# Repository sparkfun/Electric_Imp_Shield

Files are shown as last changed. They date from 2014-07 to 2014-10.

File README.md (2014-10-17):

Electric Imp Shield
===================

[Electric Imp Shield
*Electric Imp Shield (DEV-12887)*](https://www.sparkfun.com/products/12887)

The Electric Imp shield allows you to connect your Arduino to the Imp Cloud Service and connect to HTTP APIs. 

Repository Contents
-------------------
* **/Hardware** - All Eagle design files (.brd, .sch)
* **/Production** - Test bed files and production panel files

Product Versions
----------------
* [DEV-11401](https://www.sparkfun.com/products/retired/11401)- Version 1.1. Designed for Uno (not R3). Retired. 

Version History
---------------
* [v1.1](https://github.com/sparkfun/Electric_Imp_Shield/tree/V_1.1) Version 1.1

License Information
-------------------
The hardware is released under [Creative Commons ShareAlike 4.0 International](https://creativecommons.org/licenses/by-sa/4.0/).The code is beerware; if you see me (or any other SparkFun employee) at the local, and you've found our code helpful, please buy us a round!

Distributed as-is; no warranty is given.

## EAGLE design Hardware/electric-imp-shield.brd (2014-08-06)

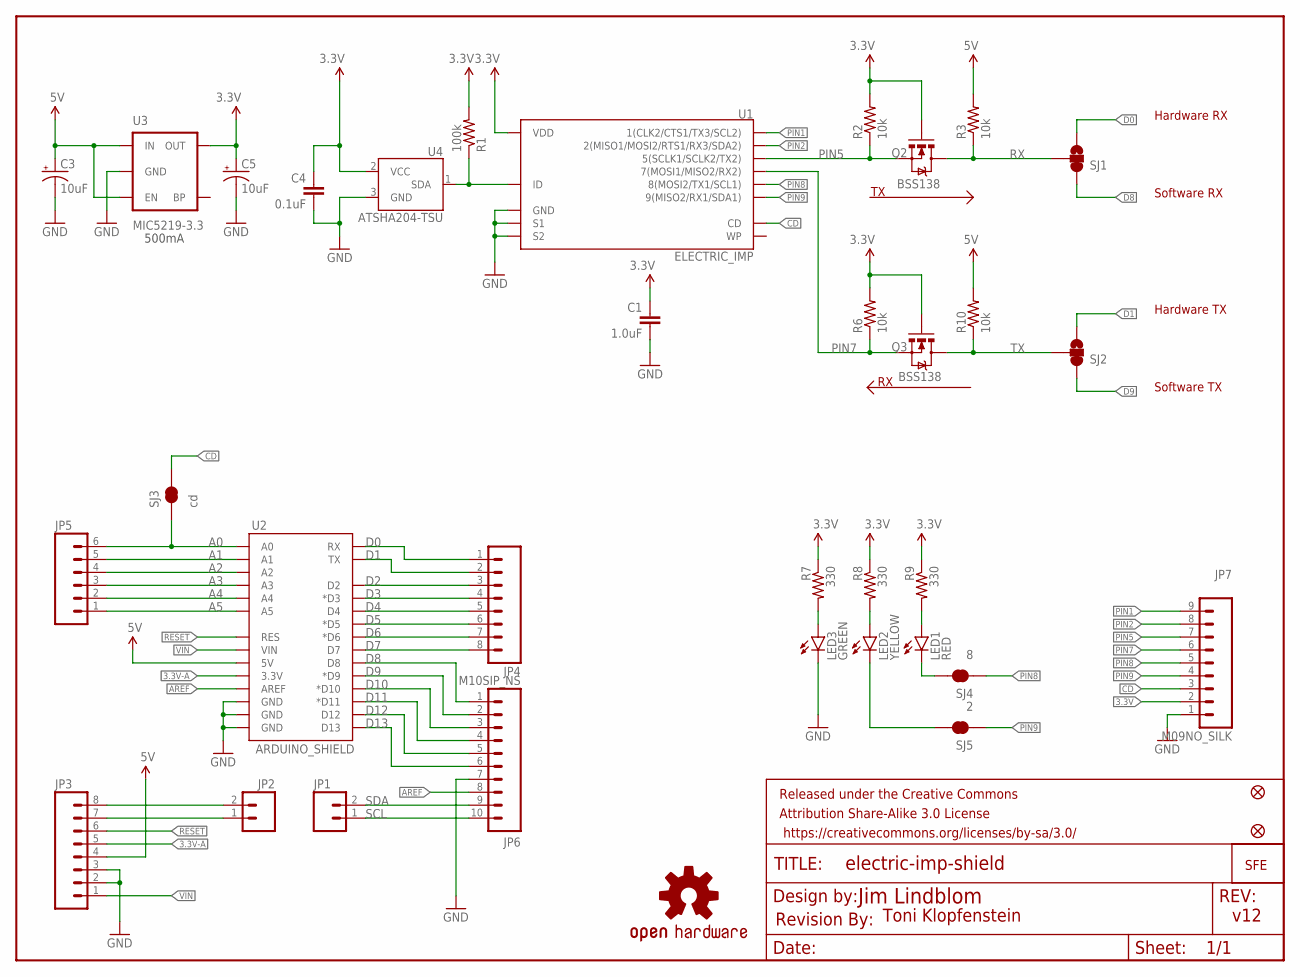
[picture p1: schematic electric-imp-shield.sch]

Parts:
C1: 1.0uF; 0603-CAP
C3, C5: 10uF; EIA3216
C4: 0.1uF; 0603-CAP
FID1, FID2: FIDUCIAL1X2; FIDUCIAL-1X2
FRAME1: FRAME-LETTER; CREATIVE_COMMONS
JP1, JP2: M021X02_NO_SILK; 1X02_NO_SILK
JP3, JP4: M08SIP_NS; 1X08_NO_SILK
JP5: M06SIP_NS; 1X06_NO_SILK
JP6: M10SIP_NS; 1X10_NO_SILK
JP7: M09NO_SILK; 1X09_NO_SILK
JP10: LOGO-SFENW2; SFE-NEW-WEB
LED1: RED; LED-0603
LED2: YELLOW; LED-0603
LED3: GREEN; LED-0603
Q2, Q3: BSS138; SOT23-3
R1: 100k; 0603-RES
R2, R3, R6, R10: 10k; 0603-RES
R7, R8, R9: 330; 0603-RES
SJ1, SJ2: SOLDERJUMPER_2WAYS; SJ_3
SJ3: cd; SJ_2S-TRACE
SJ4: 8; SJ_2S-TRACE
SJ5: 2; SJ_2S-TRACE
U1: ELECTRIC_IMP; SD_1:1
U2: ARDUINO_SHIELD; DUEMILANOVE_SHIELD_NOHOLES_NOLABELS
U3: MIC5219-3.3; SOT23-5
U4: ATSHA204-TSU; SOT23-3
U$6: REVISION
U$7: OSHW-LOGOS; OSHW-LOGO-S

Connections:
3.3V: C1.1, C4.1, C5.A (+), JP7.2, Q2.1 (G), Q3.1 (G), R1.2, R2.2, R6.2, R7.1, R8.1, R9.1, U1.4 (VDD), U3.5 (OUT), U4.2 (VCC)
3.3V-A: JP3.5, U2.3.3V
5V: C3.A (+), JP3.4, R3.2, R10.2, U2.5V, U3.1 (IN), U3.3 (EN)
A0: JP5.6, SJ3.1, U2.A0
A1: JP5.5, U2.A1
A2: JP5.4, U2.A2
A3: JP5.3, U2.A3
A4: JP5.2, U2.A4
A5: JP5.1, U2.A5
ACTIVITY: LED1.C, SJ4.2
AREF: JP6.8, U2.AREF
CD: JP7.3, SJ3.2, U1.CD
D0: JP4.1, SJ1.3, U2.RX
D1: JP4.2, SJ2.3, U2.TX
D2: JP4.3, U2.D2
D3: JP4.4, U2.D3 (*D3)
D4: JP4.5, U2.D4
D5: JP4.6, U2.D5 (*D5)
D6: JP4.7, U2.D6 (*D6)
D7: JP4.8, U2.D7
D8: JP6.1, SJ1.1, U2.D8
D9: JP6.2, SJ2.1, U2.D9 (*D9)
D10: JP6.3, U2.D10 (*D10)
D11: JP6.4, U2.D11 (*D11)
D12: JP6.5, U2.D12
D13: JP6.6, U2.D13
GND: C1.2, C3.C (-), C4.2, C5.C (-), JP3.2, JP3.3, JP6.7, JP7.1, LED3.C, U1.3 (GND), U1.SH@1 (S1), U1.SH@2 (S2), U2.GND@0 (GND), U2.GND@1 (GND), U2.GND@2 (GND), U3.2 (GND), U4.3 (GND)
LINK: LED2.C, SJ5.2
unnamed: R1.1, U1.6 (ID), U4.1 (SDA)
unnamed: JP2.2, JP3.8
unnamed: JP2.1, JP3.7
unnamed: LED3.A, R7.2
unnamed: LED2.A, R8.2
unnamed: LED1.A, R9.2
PIN1: JP7.9, U1.1 (1(CLK2/CTS1/TX3/SCL2))
PIN2: JP7.8, U1.2 (2(MISO1/MOSI2/RTS1/RX3/SDA2))
PIN5: JP7.7, Q2.2 (S), R2.1, U1.5 (5(SCLK1/SCLK2/TX2))
PIN7: JP7.6, Q3.2 (S), R6.1, U1.7 (7(MOSI1/MISO2/RX2))
PIN8: JP7.5, SJ4.1, U1.8 (8(MOSI2/TX1/SCL1))
PIN9: JP7.4, SJ5.1, U1.9 (9(MISO2/RX1/SDA1))
RESET: JP3.6, U2.RES
RX: Q2.3 (D), R3.1, SJ1.2
SCL: JP1.1, JP6.10
SDA: JP1.2, JP6.9
TX: Q3.3 (D), R10.1, SJ2.2
VIN: JP3.1, U2.VIN

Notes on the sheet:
Hardware RX
Software RX
Hardware TX
Software TX
500mA
Jim Lindblom
v12
Toni Klopfenstein

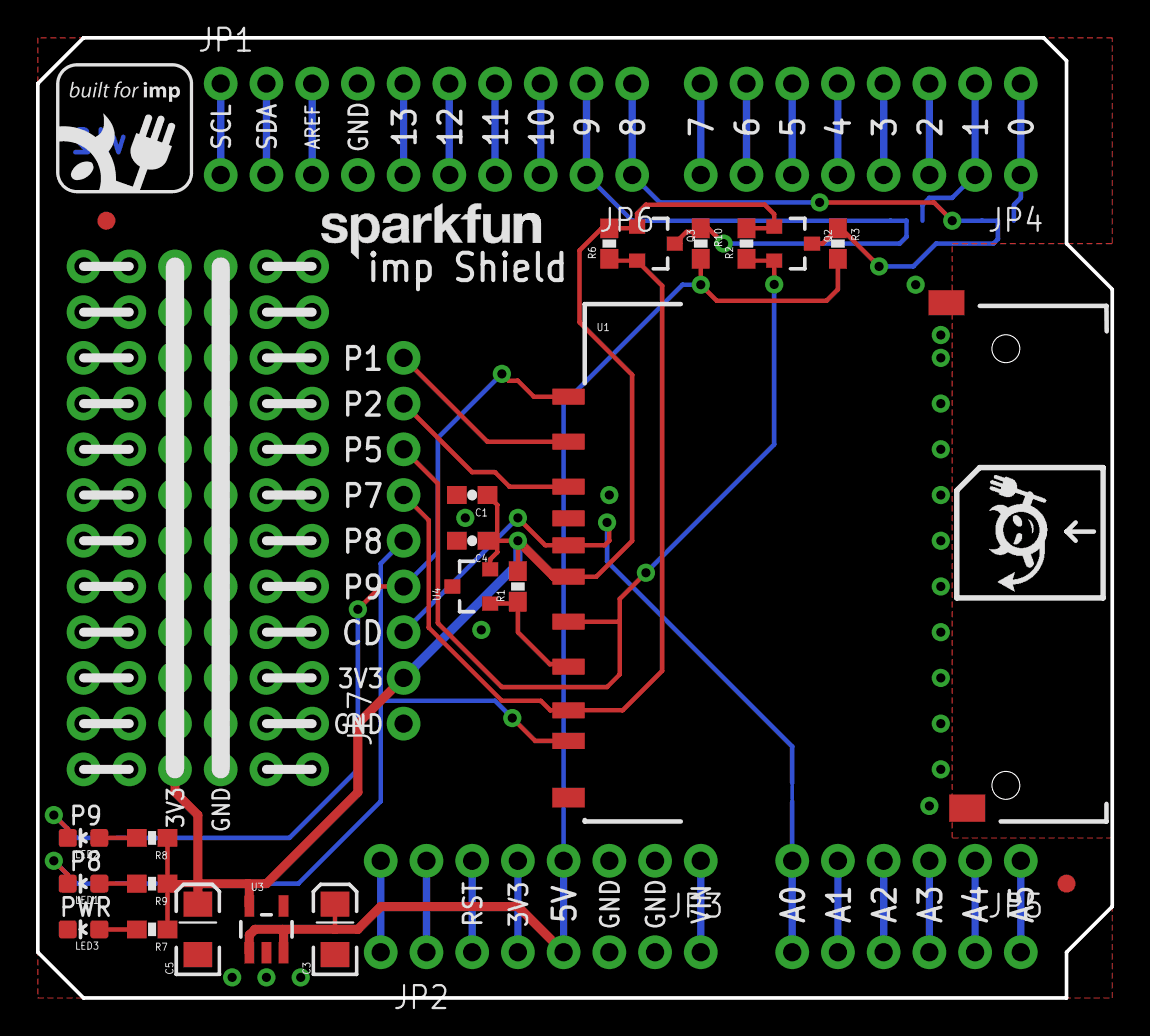
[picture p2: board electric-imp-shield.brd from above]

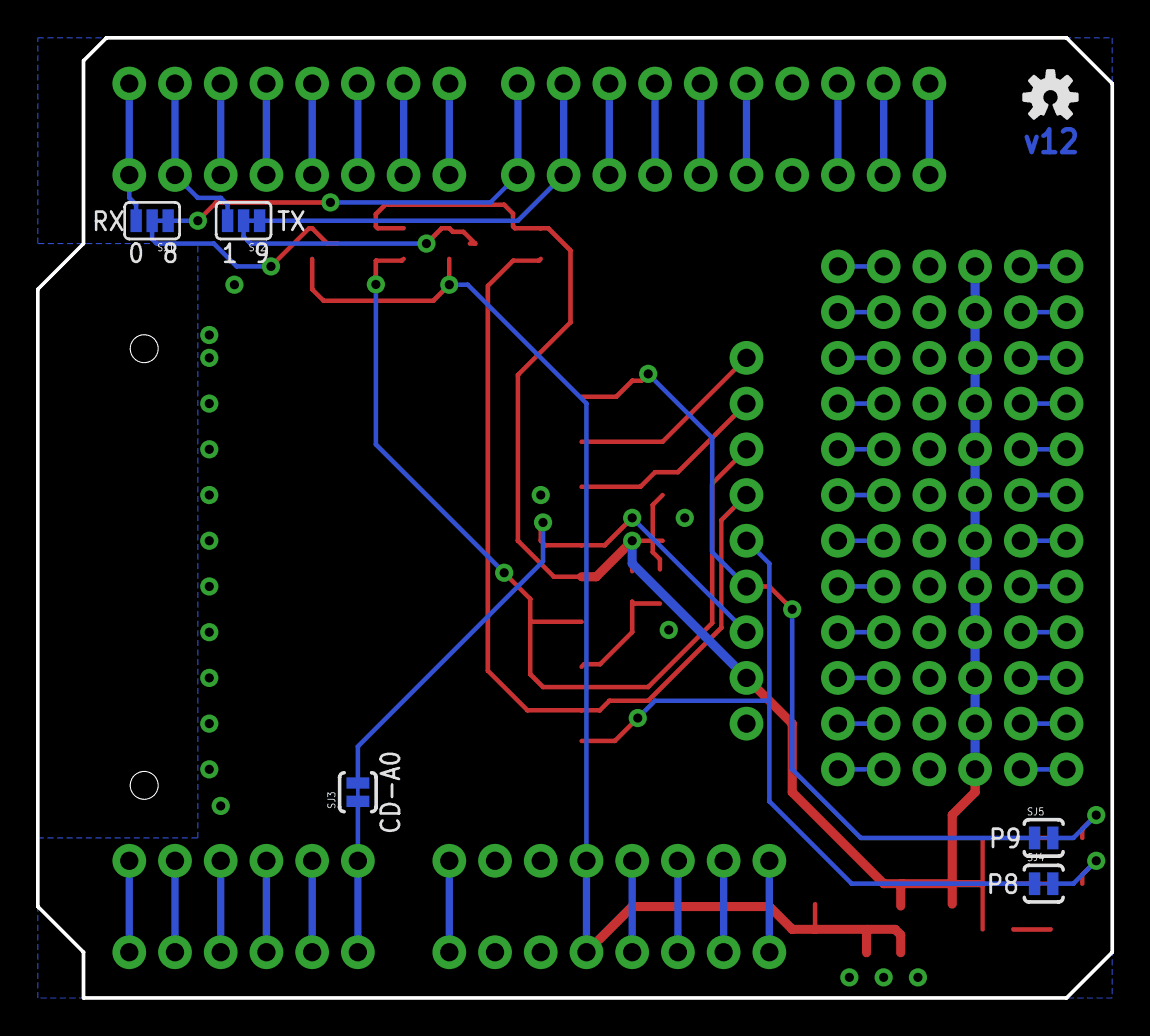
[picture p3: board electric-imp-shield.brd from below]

Board: 2 copper layers, 59.7 x 53.3 mm, 39 parts (6 on the bottom side), 46 nets.

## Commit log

2014-07-03 Adding readme and hardware files
    [electric-imp-shield-v11.brd, electric-imp-shield-v11.sch]
2014-07-03 Updating to new socket fp, 0603 packages, schematic updates
    [electric-imp-shield.brd, electric-imp-shield.sch]
2014-07-07 Fixing airwire
    [electric-imp-shield.brd]
2014-08-06 removed micro fids, added regulars
    [electric-imp-shield.brd, electric-imp-shield.sch]
2014-08-06 Fixing copper version number
    [electric-imp-shield.brd]

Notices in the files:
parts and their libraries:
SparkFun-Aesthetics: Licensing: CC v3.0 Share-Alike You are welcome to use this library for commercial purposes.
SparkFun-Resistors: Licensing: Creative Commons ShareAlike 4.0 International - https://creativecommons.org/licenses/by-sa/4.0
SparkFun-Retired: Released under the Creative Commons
